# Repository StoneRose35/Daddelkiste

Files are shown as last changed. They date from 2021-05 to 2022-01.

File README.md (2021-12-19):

## Overview

The Daddelkiste consists of a Raspberry Pi 4 connected to the official RPi-Display mounted in a Wooden frame. An Arduino Leonardo drives an additional 4X20 Character LCD display showing CPU temperature, Supply Voltage and various other informations. 
A unique feature is the simple on/off switch mechanism with low standby power consumption. For this another Atmega8 microprocessor is used. The design also features fan control which activates a fan at a certain threshold temperature, as well as a volume control with analog feel.

## Installation
Install python3. Add module "evdev" as root, specifically do "sudo pip3 install evdev".
A default user "pi" is assumed, furthermode retropie is assumed to be installed in /opt.
Replace the file /opt/retropie/configs/all/autostart.sh with the one in the repo.
Create the file /opt/retropie/startup.config, assign "users" group, grant read and write access to the group.
Copy "hardware_extension.sh" and "hdmiSwitcher.sh" into /etc/init.d/, make both executable.

## Schematic

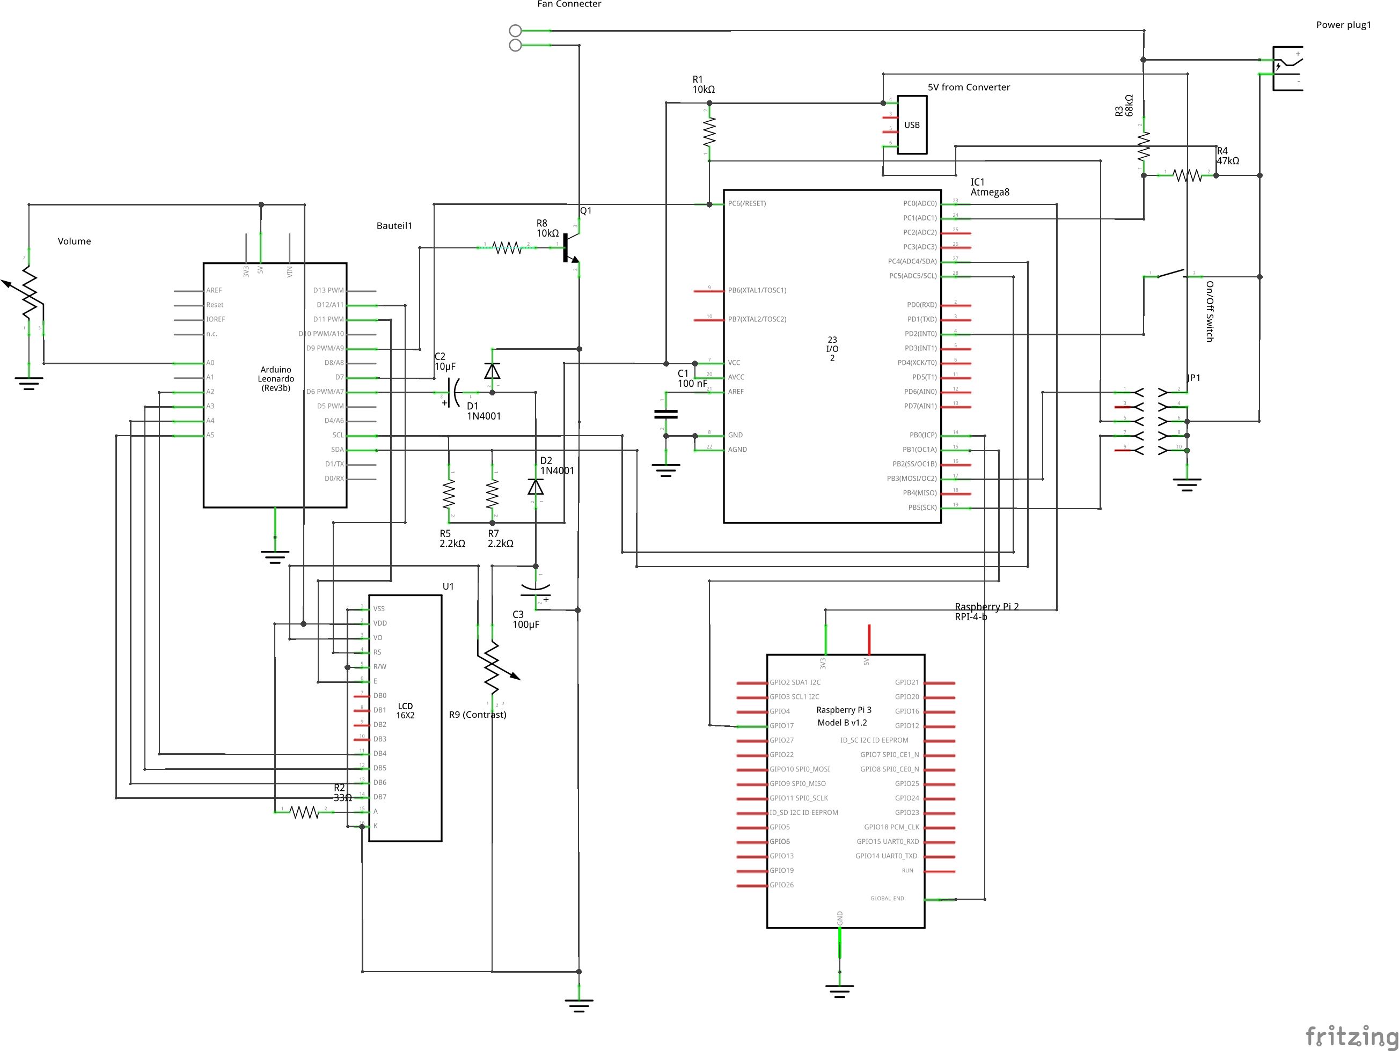
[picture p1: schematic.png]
Schematic


## Protocols / Communication

### Raspberry Pi <-> Arduino
The Raspberry Pi and the Arduino communicate over Serial USB. The possible messages received by the Arduino are as follows
* F<number from 0 to 255>\n: Sets the Fan to a specific speed, 0 is off, 255 is full speed
* A<0 or 1>\n: Switches the audio amplifier off or on, 0 is off 1 is on
* D<0 to 3><Text (max 20 chars)>\n: Display the given information on a certain line, ex. "D1CPU Speed: 788MHz\n" displays "CPU Speed: 788MHz" on the second line
* V: Return the Volume Pot reading
* B: Return button push length
* S: Request battery voltage reading, this is translated into 0x02 sent over i2c
* Q: Initialize I2C Communication between Arduino and PowerController
* I: Initialize the LCD Display
* J: Reset Power Controller: Pulls the reset Pin on the PowerController, used in cases when the i2c communication ist stuck during startup

The Arduino send the following commands to the Raspberry pi
* VOL(<number from 0 to 1023>)\n: passes the reading of the volume pot to the raspberry pi
* BAT(<number from 0 to 1023>)\n: passes the reading of the supply voltage measurement to the raspberry pi
* BUT(<1 or 2>)\n: passes the reading of the button push length from the startup button, adjusts /opt/retropie/startup.config to start either emulationstation or the desktop environment

### Arduino <-> Atmega
The Arduino  and the Atmega communication over i2c with the Arduino only acting as master and the atmega8 only as slave. The commands exchanged are as follows:
* 0x00: Switch the audio amp off
* 0x01: Switch the audio amp on
* 0x02: Request Battery Voltage reading, two bytes must be requested after having issued this command
* 0x03: Request Button Push length, one byte must be requested after having issued this command, 1: short push, starts emulationstation, 2: long push: starts normal desktop environment

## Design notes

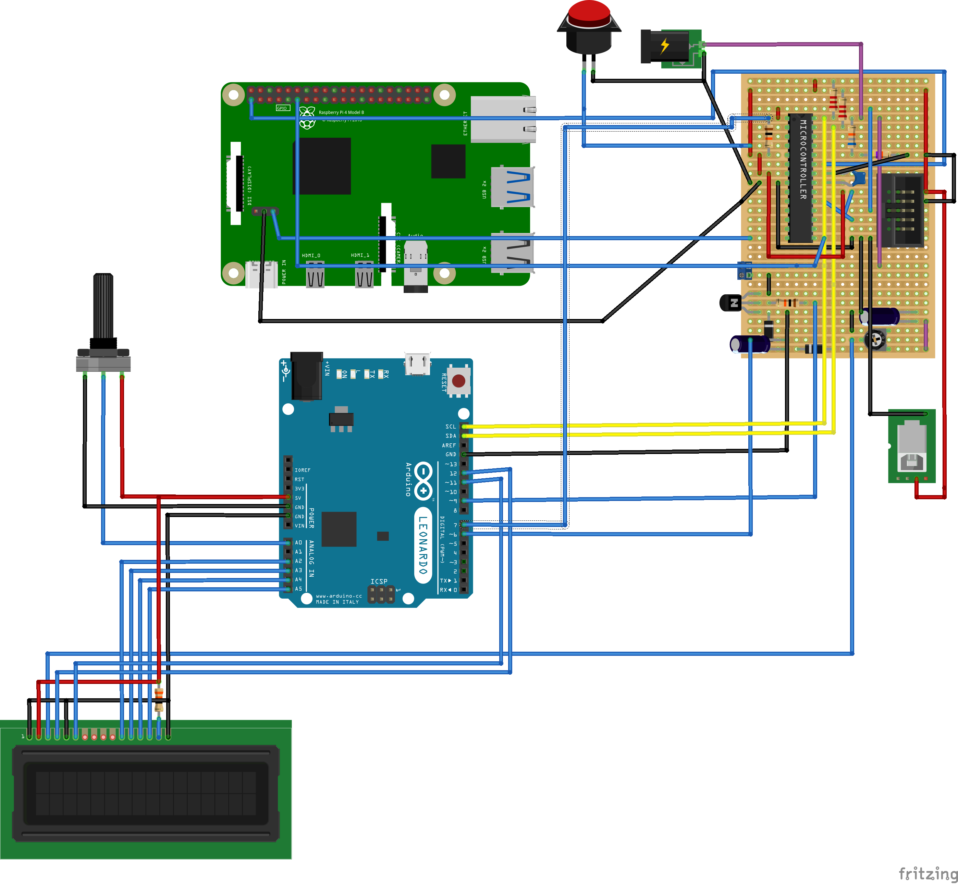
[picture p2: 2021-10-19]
breadboard.png

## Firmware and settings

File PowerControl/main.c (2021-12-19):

/*
 * DaddelkistePowercontrol.c
 *
 * Created: 03.05.2021 18:04:11
 * Author : fuerh
 */ 


#include "system.h"
#include <avr/io.h>
#include <avr/interrupt.h>
#include <avr/sleep.h>
#include <avr/wdt.h>
#include <util/delay.h>
#include "timers.h"
#include "wdtConfig.h"

#define nop() asm volatile("nop")

// task id's for the main, denote individual bits
#define HANDLE_BUTTON 1
#define HANDLE_BUTTON_LONG 2
#define READ_BATTERY_VOLTAGE 3
#define SEND_BATTERY_VOLTAGE_MSB 4
#define GO_TO_SLEEP 5
#define SEND_BUTTON_PUSH_LENGTH 6
#define SEND_BATTERY_VOLTAGE_LSB 7
#define NOTHING 0

// button press length states

// pinout
//rpi 3.3v sense: ADC0 (pin 23)
// battery voltage sense: ADC1 (pin24)
// switch: int0/pd2 (pin4)
// rpi global_en: PB0 (pin14)
// rpi shutdown: PB1 (pin15)
// audio amp switch: PD7 (pin 13) 

volatile uint8_t last_cmd;
volatile uint16_t bat_voltage;
volatile uint8_t task;
volatile uint8_t buttonPushLength=1; // 1: short, 2: long
volatile uint8_t timerOverflown = 0;
volatile uint8_t transmissionOngoing = 0;


void readBatVoltage()
{
	// read battery voltage
	ADMUX &= ~0xF;
	ADMUX |= (1 << MUX0);
	ADCSRA |= (1 << ADSC) | (1 << ADIF);
	while ((ADCSRA & (1 << ADIF)) == 0)
	{
	}
	bat_voltage = ADC;
	task &= ~(1 << READ_BATTERY_VOLTAGE);
}

void sendBatteryMsb()
{
	TWDR = (bat_voltage >> 8) & 0xFF;
	TWCR |= (1 << TWEA) | (1 << TWINT) | (1 << TWEN);
	task &= ~(1 << SEND_BATTERY_VOLTAGE_MSB);
	transmissionOngoing = 1;
}

void sendBatteryLsb()
{
	TWDR = bat_voltage & 0xFF;
	TWCR &= ~(1 >> TWEA);
	TWCR |= (1 << TWINT) | (1 << TWEN);
	task &= ~(1 << SEND_BATTERY_VOLTAGE_LSB);
	transmissionOngoing = 0;
}

void sendButtonPushLength()
{
	TWDR = buttonPushLength;
	TWCR &= ~(1 >> TWEA);
	TWCR |= (1 << TWINT) | (1 << TWEN);
	task &= ~(1 << SEND_BUTTON_PUSH_LENGTH);
	transmissionOngoing = 0;
}

void handleButtonPush()
{
	uint16_t rpi_sense;
	
	// read rpi 3.3v sense
	ADMUX &= ~0xF;
	ADCSRA |= (1 << ADSC)| (1 << ADIF);
	while ((ADCSRA & (1 << ADIF)) == 0)
	{
	}
	rpi_sense = ADC;

	if (rpi_sense > 100)
	// raspberry pi  is on --> switch off
	{

		
		PORTD &= ~(1 << PD7); // audio amp off
		PORTB &= ~(1 << PB1);
		DDRB |= (1 << DDB1);
		_delay_ms(10.0);
		DDRB &= ~(1 << DDB1);
		
		/*
		// wait until raspberry pi is switched off before switching off the twi
		while (rpi_sense > 100)
		{
			ADMUX &= ~0xF;
			ADCSRA |= (1 << ADSC)| (1 << ADIF);
			while ((ADCSRA & (1 << ADIF)) == 0)
			{
			}
			rpi_sense = ADC;
		}
		// switch off TWI/i2c
		PORTD &= ~0x1;
		TWCR &= ~((1 << TWEN) | (1 << TWEA));
		*/
	}
	else
	{
		readBatVoltage();
		if (bat_voltage > BAT_TH)
		{
			// switch off TWI/i2c initially
			PORTD &= ~0x1;
			TWCR &= ~((1 << TWEN) | (1 << TWEA));
					
			PORTD &= ~0x2;
			PORTD &= ~(1 << PD7); // audio amp off
			PORTB &= ~(1 << PB0);
			DDRB |= (1 << DDB0);
			_delay_ms(10);
			DDRB &= ~(1 << DDB0);
			
			// read the SCL as an analog input and wait until it remains high for at two consecutive measurements 40 ms  apart
			// then switch the twi back on
			
			uint8_t n_highs = 0;		
			while (n_highs < 2)
			{
				wdt_reset();
				TCNT2 = 0;
				TCCR2 |= 0x7;
				while (TCNT2 < 39)
				{
				}
				ADMUX &= ~0xF;
				ADMUX |= (1 << MUX2) | (1 << MUX0);
				ADCSRA |= (1 << ADSC) | (1 << ADIF);
				while ((ADCSRA & (1 << ADIF)) == 0)
				{
				}
				rpi_sense = ADC;
				if (rpi_sense > 800)
				{
					n_highs++;
				}
				else
				{
					n_highs = 0;
				}
			}
			
			PORTD |= 1;
			ADMUX &= ~0xF;
			TWCR |= (1 << TWEN) | (1 << TWEA) | (1 << TWINT);
		}
	}
	task &= ~(1 << HANDLE_BUTTON);
	//PORTD |= 0x2;
}

int main(void)
{
	buttonPushLength = 1;
	uint16_t scl_level;
	  	wdt_reset();
    // setup adc
	ADCSRA = (1 << ADEN) | (1 << ADPS1) | (1 << ADPS0);
	ADMUX = (1 << REFS0);
	
	// configure debug leds on pd0 and pd1
	DDRD |= 0x3;
	PORTD &= ~0x3;
	
	// setup external interrupt
	PORTD |= (1 << PD2);
	GICR |= (1 << INT0);
	MCUCR |= 0; // active on low level

	// initialize i2c to listen to address 10
	TWAR = (I2C_ADDRESS << 1);
	
	// audio amp switch as output
	DDRD |= (1 << DDD7);
	
	TCNT1 = 0;
	
	TWCR |= (1 << TWIE);	
	// check initially if arduino is ready, if so: enable TWI/i2c
	ADMUX &= ~0xF;
	ADMUX |= (1 << MUX2) | (1 << MUX0);
	ADCSRA |= (1 << ADSC) | (1 << ADIF);
	while ((ADCSRA & (1 << ADIF)) == 0)
	{
	}
	scl_level = ADC;
	if (scl_level > 800)
	{
		PORTD |= 1;
		ADMUX &= ~0xF;
		TWCR |= (1 << TWEN) | (1 << TWEA) | (1 << TWINT);
	}
	
	// init Watchdog
	//enableWdt();

	
	sei();

    while (1) 
    {
		PORTD |=2;
    	if ((task & (1 << HANDLE_BUTTON)) == (1 << HANDLE_BUTTON))
    	{
    		handleButtonPush();
    	}
    	if ((task & (1 << READ_BATTERY_VOLTAGE)) == (1 << READ_BATTERY_VOLTAGE))
    	{
    		readBatVoltage();
    	}
    	if ((task & (1 << SEND_BATTERY_VOLTAGE_MSB)) == (1 << SEND_BATTERY_VOLTAGE_MSB))
    	{
    		sendBatteryMsb();
    	}
    	if ((task & (1 << SEND_BUTTON_PUSH_LENGTH)) == (1 << SEND_BUTTON_PUSH_LENGTH))
    	{
    		sendButtonPushLength();
    	}
		
    	if ((TCCR1B & 0x7) == 0 && transmissionOngoing == 0 && task == 0)
    	{
			
			set_sleep_mode(SLEEP_MODE_IDLE);
			//disableWdt();
			sei();
			PORTD &= ~0x3;
			sleep_mode();
    	}
		
    	//wdt_reset();

    }
}

ISR ( TIMER1_COMPA_vect )
{
	uint8_t buttonState;
	//PORTD &= ~0x2;
	buttonState = PIND & (1 << PD2);
	if (buttonState == 0)
	{
		 buttonPushLength=2;
		 TCNT1=0;
		 timerOverflown = 1;
	}
	else
	{
		timerOverflown = 0;
		TCCR1B &= ~0x7;
	}
	//PORTD |= 0x2;
}


ISR(INT0_vect)
{
	//PORTD &= ~0x2;
	if ((MCUCR & 0x3) == 0x0) // low level (result of pushing down initially)
	{
		uint16_t t_val;
		t_val = getTimer1Value();
		if (((TCCR1B & 0x7) == 0x0 || t_val > 50) && timerOverflown == 0)
		{
			startTimer1(PRESC_1024);
			MCUCR |= 0x3; // set trigger to rising edge
			task |= (1 << HANDLE_BUTTON);
			//handleButtonPush();
		}
		
	}
	else // rising edge
	{
		uint16_t t_val;
		t_val = getTimer1Value();

		if (t_val > 50 && timerOverflown == 0)
		{
			// handle short press
			buttonPushLength = 1;
		}
		else if (timerOverflown == 1)
		{
			buttonPushLength = 2;
		}
		timerOverflown = 0;
		TCNT1 = 0;
		MCUCR &=  ~0x3; // set trigger back to low
	}
}


ISR ( TWI_vect )
{
	//PORTD &= ~0x2;
	if ((TWSR & 0xF8) == 0x60)
	{
		// got own address and request to write
		// wait for command
		TWCR |= (1 << TWEA) | (1 << TWINT)| (1 << TWEN);
		transmissionOngoing = 1;
	}
	else if ((TWSR & 0xF8) == 0x80)
	{
		// command has been received
		// command are: 0: turn off audio amp
		//              1: turn on audio amp
		//              2: send battery voltage
		//              3: return button push duration
		last_cmd = TWDR;
		if (last_cmd == 0)
		{
			PORTD &= ~(1 << PD7);
			transmissionOngoing = 0;
		}
		else if (last_cmd == 1)
		{
			PORTD |= (1 << PD7);
			transmissionOngoing = 0;
		}
		else if (last_cmd == 2)
		{
			task |= (1 << READ_BATTERY_VOLTAGE);
			transmissionOngoing = 1;
		}
		TWCR |= (1 << TWINT) | (1 << TWEN) | (1 << TWEA);
	}
	else if ((TWSR & 0xF8) == 0xA8 && last_cmd == 2)
	{
		// read request has been received, last command is 2 --> send MSB of voltage reading
		sendBatteryMsb();
		transmissionOngoing = 1;
	}
	else if ((TWSR & 0xF8) == 0xA8 && last_cmd == 3)
	{
		// read request has been received, last command is 3 --> send button Push length
		sendButtonPushLength();
	}
	else if ((TWSR & 0xF8) == 0xB8 && last_cmd == 2)
	{
		// data has been sent, ACK has been received, last command is 2 --> send LSB of voltage reading
		sendBatteryLsb();
	}
	else if ((TWSR & 0xF0) == 0xC0)
	{
		// last data byte has been transmitted successfully, not ack or ack (both c0 or c8 match) have been received
		TWCR |= (1 << TWINT) | (1 << TWEN) | (1 << TWEA);
		transmissionOngoing = 0;
	}
	else
	{
		TWCR |= (1 << TWINT) | (1 << TWEN) | (1 << TWEA);
		transmissionOngoing = 0;
	}
	//PORTD |= 0x2;
}

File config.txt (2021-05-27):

# For more options and information see
# http://rpf.io/configtxt
# Some settings may impact device functionality. See link above for details

# uncomment if you get no picture on HDMI for a default "safe" mode
#hdmi_safe=1

# uncomment this if your display has a black border of unused pixels visible
# and your display can output without overscan
#disable_overscan=1

# uncomment the following to adjust overscan. Use positive numbers if console
# goes off screen, and negative if there is too much border
#overscan_left=16
#overscan_right=16
#overscan_top=16
#overscan_bottom=16

# uncomment to force a console size. By default it will be display's size minus
# overscan.
#framebuffer_width=1280
#framebuffer_height=720

# uncomment if hdmi display is not detected and composite is being output
#hdmi_force_hotplug=1

# uncomment to force a specific HDMI mode (this will force VGA)
#hdmi_group=1
#hdmi_mode=1

# uncomment to force a HDMI mode rather than DVI. This can make audio work in
# DMT (computer monitor) modes
#hdmi_drive=2

# uncomment to increase signal to HDMI, if you have interference, blanking, or
# no display
#config_hdmi_boost=4

# uncomment for composite PAL
#sdtv_mode=2

#uncomment to overclock the arm. 700 MHz is the default.
#arm_freq=800

# Uncomment some or all of these to enable the optional hardware interfaces
#dtparam=i2c_arm=on
#dtparam=i2s=on
#dtparam=spi=on

# Uncomment this to enable infrared communication.
#dtoverlay=gpio-ir,gpio_pin=17
#dtoverlay=gpio-ir-tx,gpio_pin=18

# Additional overlays and parameters are documented /boot/overlays/README

# Enable audio (loads snd_bcm2835)
dtparam=audio=on
#dtparam=audio=off

[pi4]
# Enable DRM VC4 V3D driver on top of the dispmanx display stack
dtoverlay=vc4-fkms-v3d
max_framebuffers=2

[all]
#dtoverlay=vc4-fkms-v3d
gpu_mem=256

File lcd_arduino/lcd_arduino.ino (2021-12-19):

// include the library code:
#include <LiquidCrystal.h>
#include <Wire.h>
#define wdr() __asm__ __volatile__ ("wdr")


// initialize the library by associating any needed LCD interface pin
// with the arduino pin number it is connected to
//const int rs = 12, en = 11, d4 = 5, d5 = 4, d6 = 3, d7 = 2;
const int rs = 12, en = 11, d4 = A2, d5 = A3, d6 = A4, d7 = A5;
const int fan = 9;
const int contrast_gen = 6;
const int atmega_twi_addr = 10;
const int resetline = 7;


LiquidCrystal lcd(rs, en, d4, d5, d6, d7);
int volumeOld=0;
unsigned int cntr=0; 
int bat_voltage = 0;
int fanSpeed;
int buttonPushLength = 0; // 1: short, 2: long

void sendVolume(int val)
{
      String sentValue;
      sentValue = "VOL(";
      sentValue += val;
      sentValue += ")\n";
      Serial.print(sentValue);
}

void readBattery()
{
      Wire.beginTransmission(atmega_twi_addr);
      Wire.write(2);
      int retcode = Wire.endTransmission();
      if(retcode!=0)
      {
        returnErrorCode(retcode);
      }
      delay(2);
      int bytes_returned = Wire.requestFrom(atmega_twi_addr,2);
      if (bytes_returned != 2)
      {
        returnErrorCode(bytes_returned + 10);
      }
      bat_voltage=0;
      int factor = 256;
      while (Wire.available()) {
        char c = Wire.read();
          bat_voltage = bat_voltage + factor * c;
          factor /= 256;
      }
      String bat_msg = "BAT(";
      bat_msg += bat_voltage;
      bat_msg += ")\n";
      Serial.print(bat_msg);
}

void returnErrorCode(int code)
{
        String err_msg = "ERR(";
        err_msg += code;
        err_msg += ")\n";
        Serial.print(err_msg);    
}

void initWatchdog()
{
  //cli();
  wdr();
  WDTCSR |= (1<<WDCE) | (1<<WDE); // has to be done in one instruction, see data sheet
  WDTCSR  = (1<<WDE) | (1<<WDP2) | (1<<WDP1) | (0<<WDIE); // watchdog is set to 1s 
}

void setup() {

  // generate a square wave for the constrast voltage
  analogWrite(contrast_gen,128);

  // predefine reset line to output zero if defined as output
  digitalWrite(resetline,0);

  //slow down PWM Frequency
  TCCR1B&=0b11111000;
  TCCR1B|=0b00000100; 

  // 3.3v reference for the volume pot
  analogReference(EXTERNAL);
  
  delay(50);

  // set up the LCD's number of columns and rows:
  lcd.begin(20, 4);
  // Print a message to the LCD.
  lcd.print("Daddelkiste booting");
  delay(2);
  Serial.begin(9600);

}

void loop() {

  int volumeValue = analogRead(A0);
  if (volumeValue > volumeOld)
  {
    if (volumeValue - volumeOld > 4)
    {
      sendVolume(volumeValue);

      volumeOld = volumeValue;
    }
  }
  else if ( volumeValue < volumeOld) 
  {
    if (volumeOld - volumeValue > 4)
    {
     sendVolume(volumeValue);
     wdr();
      volumeOld = volumeValue;
    }
  }

  if (Serial.available() > 0)
  {
    String data = Serial.readStringUntil('\n');
    wdr();
    if (data.startsWith("F"))
    {
      // command for setting the fan speed
      fanSpeed = data.substring(1).toInt();
      analogWrite(fan,fanSpeed);
    }
    else if (data.startsWith("D"))
    {
      int linenr = data.substring(1,2).toInt();
      lcd.setCursor(0, linenr);
      lcd.print("                    ");
      lcd.setCursor(0, linenr);
      lcd.print(data.substring(2));
    }
    else if (data.startsWith("A"))
    {
      Wire.beginTransmission(atmega_twi_addr);
      // toggle audio amplifier
      if (data.substring(1).toInt()==0)
      {
          Wire.write(0);
      }
      else
      {
          Wire.write(1);
      }
      int retcode = Wire.endTransmission();  
      if(retcode!=0)
      {
        returnErrorCode(retcode);
      }
    }
    else if (data.startsWith("V"))
    {
      sendVolume(volumeOld);
    }
    else if (data.startsWith("B"))
    {
      Wire.beginTransmission(atmega_twi_addr);
      Wire.write(3);
      int retcode = Wire.endTransmission();
      if (retcode!=0)
      {
        returnErrorCode(retcode);  
      }
      delay(2);
      int bytesreturned = Wire.requestFrom(atmega_twi_addr,1);
      while (Wire.available()) {
        buttonPushLength = Wire.read();
      }
      if (bytesreturned!= 1)
      {
        returnErrorCode(bytesreturned + 10);
      }
      String sentValue;
      sentValue = "BUT(";
      sentValue += buttonPushLength;
      sentValue += ")\n";
      Serial.print(sentValue);
    }
    else if (data.startsWith("I"))
    {
      lcd.begin(20, 4);  
    }
    else if (data.startsWith("S"))
    {
      readBattery();
      //wdr();
    }
    else if (data.startsWith("Q")) // start i2c communication
    {
      Wire.begin();  
    }
    else if (data.startsWith("J")) // pull down reset for 2 ms
    {
      pinMode(resetline,OUTPUT);
      delay(2);
      pinMode(resetline,INPUT);
      delay(2);
      Wire.begin(); 
    }
  }
}

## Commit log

2021-05-23 added battery voltage display
2021-05-23 added hysteresis to fan control, little refactoring
2021-05-23 slowed down pwm frequency for fan control
2021-05-23 added fritzing stuff
    [Daddelkiste.fzz]
2021-05-24 suppressed fan noise during volume pot reading, added initial volume pot display, refined brown out voltage
    [lcdInterface.py, lcd_arduino.ino]
2021-05-27 corrected schematic
    [Daddelkiste.fzz]
2021-05-27 added config.txt from rpi boot partition and instructions on how to edit the eeprom settings
    [config.txt]
2021-05-27 added schematic for the battery charger
    [BatteryCharger.fzz]
2021-05-28 removed fan switch off during volume pot read, adjusted fan speed values, corrected calls for volume set and shutdown
    [daddelkisteCommon.py, daddelkisteCommonTest.py, lcdInterface.py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]
2021-06-13 various changes regarding fan speed computation, added delay for stabilized startup of the arduino
    [daddelkisteCommon.py, lcd_arduino.ino]
2021-08-22 added switch script to automatically change to hdmi output as primary output
2021-09-03 added watchdog functionality for the arduino part
2021-09-06 moved main to PowerControl
2021-09-06 bugfixed the hdmi-Switcher
2021-09-06 added watchdog to avoid blocked situations
    [main.c]
2021-09-06 added long/short button push functionality, a long button push open the desktop, a short button push starts emulationstation
    [lcdInterface.py, lcd_arduino.ino]
2021-09-06 switched to timer1 for button timing (debounce and button length measurement)
2021-09-09 corrected wdt handling, power controller now works again
    [main.c]
2021-09-13 major startup sequence cleanup instead of timing the i2c controller (which is unstable as long as the arduino is switched off) is now enabled only when the voltage in the scl pin is hight for twice 4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
    [main.c]
2021-09-13 added new commands: "Q": initiate I2C Communication (must be issued before "S", "A" or "B") "S": Read battery voltage "B": Read button press duration (either 1: short or 2: long) "I": reinit the disp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
    [lcd_arduino.ino]
2021-09-13 added new command to lcdInterface fix for avoiding immediate shutdown if zero is returned from the avr as a result of the battery voltage reading
    [daddelkisteCommon.py, lcdInterface.py]
2021-09-15 improved winding down of the i2c communication when switching off
2021-09-22 added timeout for serial connection to avoid blocking
    [lcdInterface.py]
2021-10-19 added reset functionality for atmel power controller
    [lcd_arduino.ino]
2021-10-19 added reset command when i2c communication fails
    [lcdInterface.py]
2021-10-19 corrected mistakes in "avr reset" call if i2c fails on startup
    [lcdInterface.py]
2021-10-19 Added reinit of i2c communication before powercontrol restart
2021-10-19 update schematic
    [Daddelkiste.fzz]
2021-10-20 added autostart, corrected readme, fixed a typo in py-file
    [lcdInterface.py]
2021-10-22 added driver for hardware digital joystick
2021-10-23 defined meaningful gpio pins, added logging fixed a bug regarding the power controller restart
    [joystickHandler.py, lcdInterface.py]
2021-10-26 changed fal threshhold temperatures
2021-10-26 bugfixes in the lcdInterface controller
    [daddelkisteCommon.py, lcdInterface.py]
2021-10-26 fixed joystick driver, simplified and corrected fan controller
    [daddelkisteCommon.py, joystickHandler.py]
2021-10-27 readded stabilization logics, defaulting to button push length 1 enabled and change power saving mode
2021-11-09 removed switching off twi when powering off
2021-12-19 added label sheet for buttons
    + commit of minor changes in arduino sketch
